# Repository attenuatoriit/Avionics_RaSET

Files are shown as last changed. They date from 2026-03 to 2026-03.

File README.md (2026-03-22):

# Avionics_RaSET
This repository encompasses all the updates regarding the rocket avionics (MaxQ) that has beendeveloped in house by the IIT Kanpur Rocketry and Space Exploration Team. The avionics has been designed keeping in mind Space Port America Cup 10k SRAD category. There are mainly three main components of the avionics - flight computer, arming switch and telemetry.  The flight computer encompasses the ltimeter, IMU, micro controller and GPS. It also has ports to support to different telemetry devices- Xbee and LoRA. The use of a micro processor is being planned on the flight computer in ot=rder to facilitate the implementation of trajectory plnning of the rocket during its flight.

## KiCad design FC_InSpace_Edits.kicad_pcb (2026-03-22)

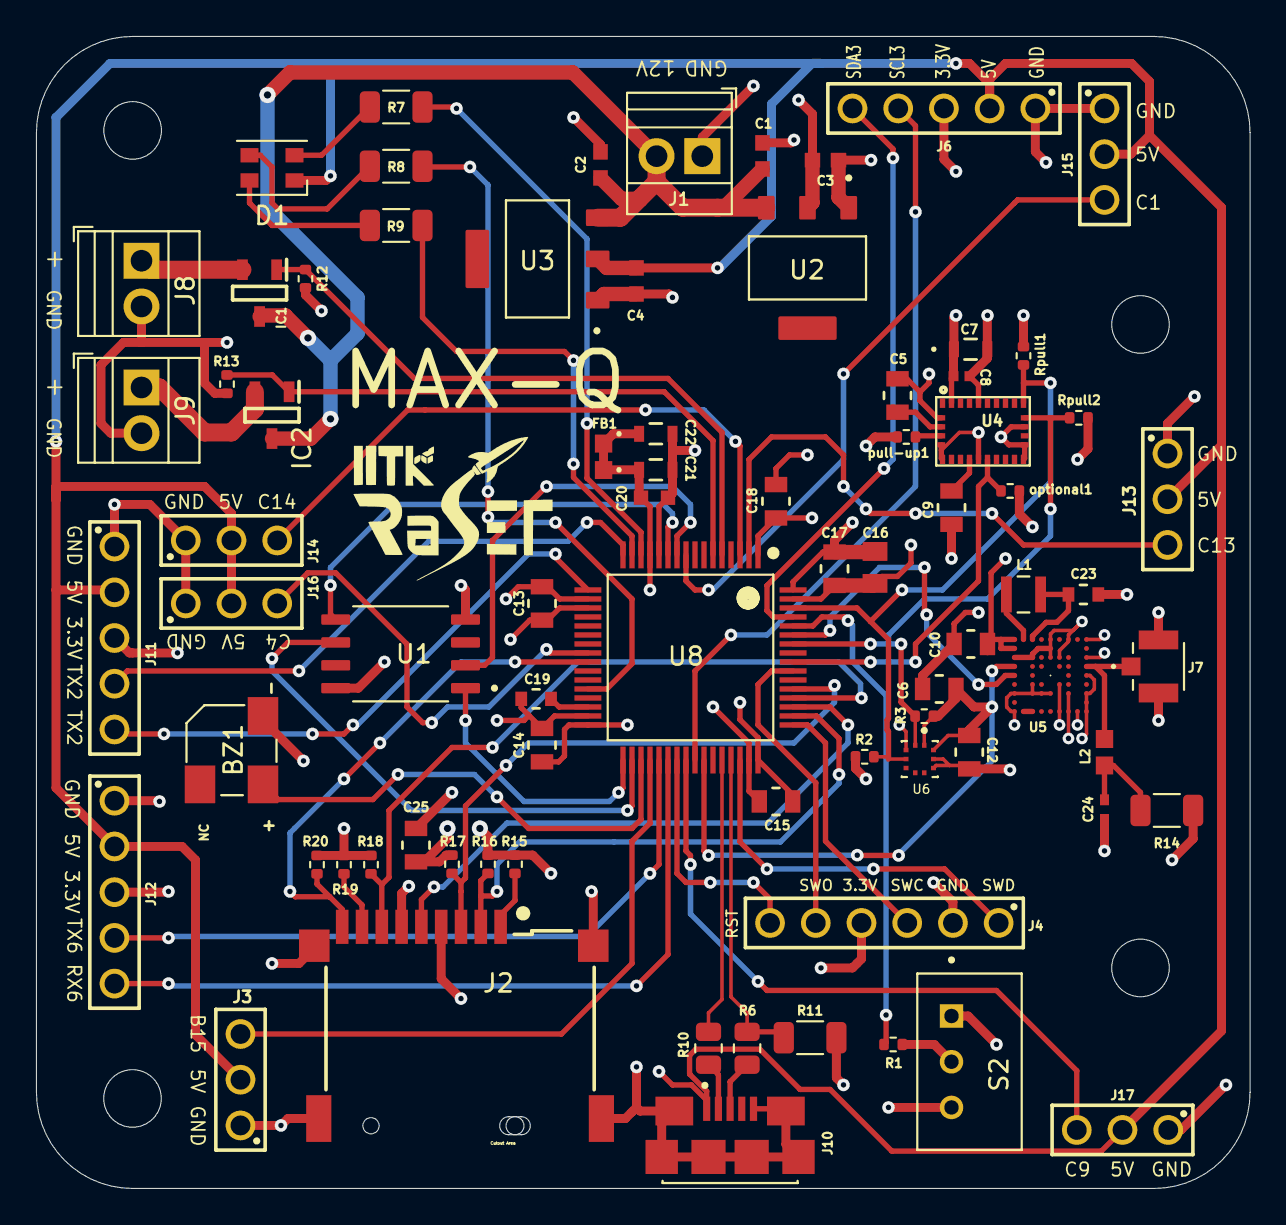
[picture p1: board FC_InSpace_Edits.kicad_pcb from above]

Board: 4 copper layers, 67.4 x 64.0 mm, 77 parts (0 on the bottom side), 62 nets.

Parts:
BZ1: Buzzer; CUI_CSS-0575B-SMT
C1, C2, C3, C4: 22u; G-188_MUR
C5, C6, C9, C12: 100nF; CAP_CL21_SAM
C7: 6.8nF; CAP_1608_TDK
C8: 120nF; CAP_CC0402_YAG
C10: 0.1 uF; CAP_CL21_SAM
C13, C14, C15, C17, C18, C25: 100n; CAP_CL21_SAM
C16: 10u; CAPC2012X135N
C19: 4.7u; CAP_CL10_SAM
C20: 10n; WCAP-CSMH_0603_R
C21, C22: 1u; CAP_1608_TDK
C23: 4.7 uF; CAP_CL10_SAM
C24: 47 pF; G-155_MUR
D1: CLV1L-FKB; LED_Cree-PLCC4_3.2x2.8mm_CCW
FB1: 120R; BEADC1608X75N
IC1, IC2: NMOS; SOT95P285X130-3N
J1: Screw_Terminal; TerminalBlock_Xinya_XY308-2.54-2P_1x02_P2.54mm_Horizontal
J2: SD Card FC; 693071020811
J3, J13, J14, J15, J16, J17: Headers 3x1 FC; 61300311121
J4: Headers ST-Link; 61300611121
J6, J11, J12: Headers 5x1 FC; 61300511121
J7: U.FL-R-SMT_10_; HRS_U.FL-R-SMT_10_
J8, J9: Screw_Terminal_01x02; TerminalBlock_Xinya_XY308-2.54-2P_1x02_P2.54mm_Horizontal
J10: MicroUSB FC; AMPHENOL_10118192-0002LF
L1: 2.2 uH; IND_VLS252012HBX-2R2M-1
L2: L_Ferrite; BEADC1608X75N
R1, R15, R16, R17, R18, R19, R20: 10k; R_0402_1005Metric
R2, R3: 4.7k; R_0402_1005Metric
R6, R10: 20; R_0805_2012Metric
R7: 150; R_1206_3216Metric
R8, R9: 130; R_1206_3216Metric
R11: 1.5k; R_1206_3216Metric
R12, R13: 10K; R_0402_1005Metric
R14: 10; R_1206_3216Metric
Rpull1, Rpull2: 10k; R_0402_1005Metric
S2: Switch2 FC; SW_MPB01-1C33-S-D
U1: W25Q128JVS; SOIC127P790X216-8N
U2: AMS1117-3.3; SOT229P700X180-4N
U3: AMS1117-5.0; SOT229P700X180-4N
U4: BNO055; LGA28R50P4X10_380X520X100
U5: ZOE-M8Q; ZOE-M8
U6: BMP390L; XDCR_BMP390L
U8: STM32F411RETx; QFP50P1200X1200X160-64N
optional1: 10k; R_0402_1005Metric
pull-up1: 10k; R_0402_1005Metric

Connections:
+3.3V: C3.1, C6.2, C7.1, C8.1, C10.1, C12.2, C13.1, C14.1, C15.1, C16.1, C17.1, C18.1, C20.1, C21.1, C22.1, C25.1, FB1.1, FB1.2, J2.4 (VDD), J4.4, J6.3, J11.3, J12.3, R2.1, R3.2, R11.2, R14.1, R15.1, R16.1, R17.1, R18.1, R19.1, R20.1, Rpull1.1, Rpull2.1, S2.1, U1.8 (VCC), U2.2 (VO), U4.28 (VDDIO), U5.P$J1 (J1_VCC), U5.P$J2 (J2_VCC), U6.1 (VDDIO), U6.10 (VDD), U8.1 (VBAT), U8.13 (VDDA), U8.19 (VDD), U8.32 (VDD), U8.48 (VDD), U8.64 (VDD), optional1.1, pull-up1.1
+5V: C4.1, D1.1 (A), J3.2, J6.2, J10.1 (VCC), J11.2, J12.2, J13.2, J14.2, J15.2, J16.2, J17.2, U3.2 (VO)
/BOOT0: R1.1, U8.60 (BOOT0)
/BUZZER: BZ1.1, U8.35 (PB14)
/D+: R6.2, R11.1, U8.45 (PA12)
/D-: R10.2, U8.44 (PA11)
/FLASHMEM_CS: U1.1 (~CS), U8.33 (PB12)
/FLASHMEM_MISO: U1.2 (DO(IO1)), U8.10 (PC2)
/FLASHMEM_MOSI: U1.5 (DI(IO0)), U8.11 (PC3)
/FLASHMEM_SCLK: U1.6 (CLK), U8.34 (PB13)
/H1: J3.3, U8.36 (PB15)
/H2: J13.3, U8.2 (PC13)
/H3: J14.3, U8.3 (PC14)
/H4: J15.3, U8.9 (PC1)
/H5: J16.3, U8.24 (PC4)
/H7: J17.3, U8.40 (PC9)
/I2C3_SCL: J6.4, U8.41 (PA8)
/I2C3_SDA: J6.5, U8.61 (PB8)
/IMU_RESET: U4.11 (~RESET), U8.56 (PB4), optional1.2
/L1_BLU: R9.1, U8.15 (PA1)
/L1_GRE: R8.1, U8.28 (PB2)
/L1_RED: R7.1, U8.14 (PA0)
/PYRO_1: IC1.1 (G), R12.1, U8.5 (PH0)
/PYRO_2: IC2.1 (G), R13.1, U8.6 (PH1)
/SD_CS: J2.2 (CD/DAT3), R16.2, U8.50 (PA15)
/SD_DET: J2.9 (CDSW1), R20.2, U8.25 (PC5)
/SD_MISO: J2.7 (DAT0), R18.2, U8.52 (PC11)
/SD_MOSI: J2.3 (CMD), R17.2, U8.53 (PC12)
/SD_SCLK: J2.5 (CLK), U8.51 (PC10)
/USART1_RX: U5.P$J5 (J5_TXD/SPI_MISO), U8.59 (PB7)
/USART1_TX: U5.P$J4 (J4_RXD/SPI_MOSI), U8.42 (PA9)
/USART2_RX: J11.5, U8.17 (PA3)
/USART2_TX: J11.4, U8.16 (PA2)
/USART6_RX: J12.5, U8.38 (PC7)
/USART6_TX: J12.4, U8.37 (PC6)
GND: BZ1.2, C1.2, C2.2, C3.2, C4.2, C5.2, C6.1, C7.2, C8.2, C9.1, C10.2, C12.1, C13.2, C14.2, C15.2, C16.2, C17.2, C18.2, C19.1, C20.2, C21.2, C22.2, C23.1, C24.2, C25.2, J1.1, J2.6 (VSS), J2.10 (GND), J2.11 (GND), J2.12 (GND), J2.13 (GND), J3.1, J4.2, J6.1, J7.2, J7.3, J8.2, J9.2, J10.5 (GND), J10.S1 (SHIELD), J10.S2 (SHIELD), J10.S3 (SHIELD), J10.S4 (SHIELD), J10.S5 (SHIELD), J10.S6 (SHIELD), J11.1, J12.1, J13.1, J14.1, J15.1, J16.1, J17.1, R12.2, R13.2, S2.3, U1.4 (GND), U2.1 (GND), U3.1 (GND), U4.2 (GND), U4.5 (PS1), U4.6 (PS0), U4.10 (BL_IND), U4.15 (GNDIO), U4.16 (GNDIO), U4.18 (COM2), U4.25 (GNDIO), U5.P$2E1 (E1_SQI_CLK), U5.P$A1 (A1_GND), U5.P$A3 (A3_GND), U5.P$A5 (A5_GND), U5.P$A7 (A7_GND), U5.P$A8 (A8_GND), U5.P$A9 (A9_GND), U5.P$B9 (B9_GND), U5.P$C1 (C1_SQI_D1), U5.P$C7 (C7_GND), U5.P$C9 (C9_GND), U5.P$D3 (D3_SQI_CS_N), U5.P$D6 (D6_GND), U5.P$D9 (D9_GND), U5.P$E3 (E3_SQI_D2), U5.P$E7 (E7_GND), U5.P$F7 (F7_GND), U5.P$G3 (G3_GND), U5.P$G6 (G6_GND), U5.P$G7 (G7_GND), U5.P$J3 (J3_GND), U5.P$J7 (J7_RTC_I), U5.P$J9 (J9_GND), U6.3 (VSS/GND), U6.8 (VSS/GND), U6.9 (VSS/GND), U8.12 (VSSA), U8.18 (VSS), U8.31 (VSS), U8.47 (VSS), U8.63 (VSS)
unnamed: C24.1, L2.1, R14.2
unnamed: D1.4 (BK), R9.2
unnamed: D1.3 (GK), R8.2
unnamed: D1.2 (RK), R7.2
unnamed: IC1.2 (S), J8.1
unnamed: IC2.2 (S), J9.1
unnamed: J2.8 (DAT1), R19.2
unnamed: J2.1 (DAT2), R15.2
unnamed: J10.3 (D+), R6.1
unnamed: J10.2 (D-), R10.1
unnamed: R1.2, S2.2
unnamed: C9.2, U4.9 (CAP)
unnamed: C5.1, U4.3 (VDD)
unnamed: U4.4 (~BOOT_LOAD_PIN), pull-up1.2
unnamed: J7.1, L2.2, U5.P$A4 (A4_RF_IN)
unnamed: U5.P$G9 (G9_RESERVED), U5.P$H9 (H9_V_BCKP)
unnamed: C23.2, L1.1, U5.P$G1 (V_CORE)
unnamed: L1.2, U5.P$H1 (V_DCDC_OUT)
unnamed: C19.2, U8.30 (VCAP1)
RST: J4.6, U8.39 (PC8)
SCL1: R3.1, Rpull2.2, U4.19 (COM1), U6.2 (SCK/SCL), U8.58 (PB6)
SDA1: R2.2, Rpull1.2, U4.20 (COM0), U6.4 (SDI/SDO/SDA), U8.62 (PB9)
SWCLK: J4.3, U8.49 (PA14)
SWDIO: J4.1, U8.46 (PA13)
SWO: J4.5, U8.55 (PB3)
VDB: C1.1, C2.1, IC1.3 (D), IC2.3 (D), J1.2, U2.3 (VI), U3.3 (VI)
